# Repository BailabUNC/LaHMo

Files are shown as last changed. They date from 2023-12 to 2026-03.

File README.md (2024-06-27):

# Laryngeal Health Monitor (LaHMo)

Relevent files for the project of Laryngeal Health Monitor (LaHMo)

**arduino_firmware** The PlatformIO code for the peripheral patch and the receiver.

**CAD** The DXF files of the initial design, laser-cuttable.

**data_analysis** Relevant code of the data analysis protocol.

**data_acquisition** The python code for parsing and visualizing the data.

**models** Pre-trained models.

**results** Output figures.

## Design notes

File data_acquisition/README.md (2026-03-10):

# LaHMo BLE Data Acquisition (Desktop)

This folder contains a local desktop app that uses **bleak** to scan/connect to BLE devices (including **LaHMo2**) and plots the incoming stream in real time while logging to disk.

## Run

```bash
python -m pip install -r requirements.txt
python -m data_acquisition.app
```

## LaHMo2 defaults

- **Service UUID**: `12fb95d1-4954-450f-a82b-802f71541562`
- **Notify characteristic UUID**: `67136980-20d0-4711-8b37-3acd0fec8e7f`

The firmware sends notifications as a UTF-8 string:

`timestamp_ms,pv0_V,pv1_V,pv2_V,pv3_V,roll_deg,pitch_deg,yaw_deg`

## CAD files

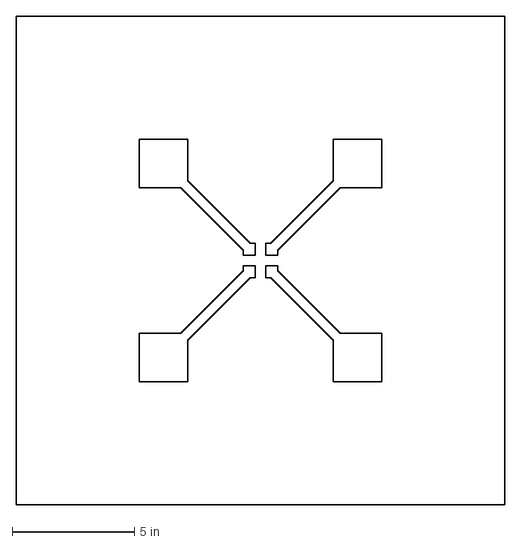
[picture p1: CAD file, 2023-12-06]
CAD/module/mosfet.dxf
20.0 x 20.0 in

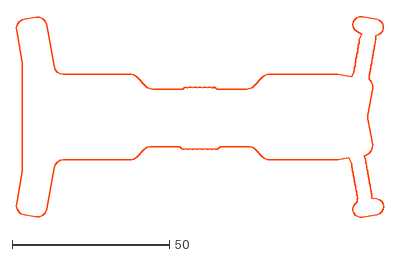
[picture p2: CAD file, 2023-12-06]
CAD/pcb_base/profile_offset.dxf
116.9 x 64.1

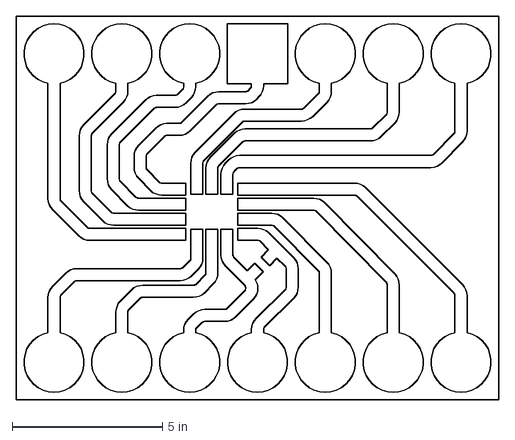
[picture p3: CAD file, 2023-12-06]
CAD/module/imu_breakout.dxf
16.0 x 12.8 in

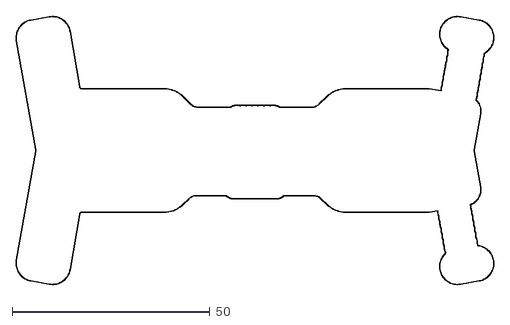
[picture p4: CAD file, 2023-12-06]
CAD/pcb_base/profile.dxf
120.8 x 67.8

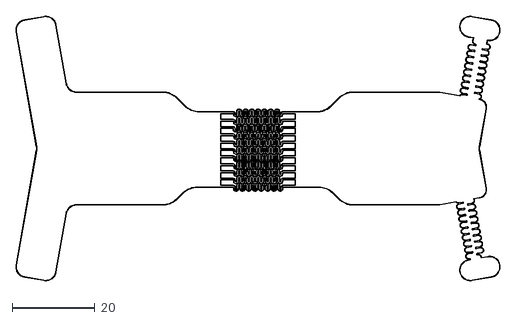
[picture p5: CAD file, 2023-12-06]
CAD/pcb_base/LSF_v3_Profile.gbr_conv.DXF
116.8 x 63.8

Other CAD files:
CAD/pcb_foldable/fold_gnd_nobranch.dwg
CAD/pcb_foldable/fold_gnd.dwg
CAD/t_shape_v3.dwg
CAD/pcb_foldable/t_shape_pi_fold_gnd.dxf
CAD/pcb_foldable/t_shape_pi.dxf
CAD/pcb_foldable/t_shape_pi_wo_marker.dxf
CAD/pcb_foldable/t_shape_pi_fold.dxf
CAD/t_shape_v2.dwg
CAD/module/mosfet.dwg
results/fig3/visualization/bevel.blend

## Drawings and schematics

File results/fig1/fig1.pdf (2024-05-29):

### PDMS

A B

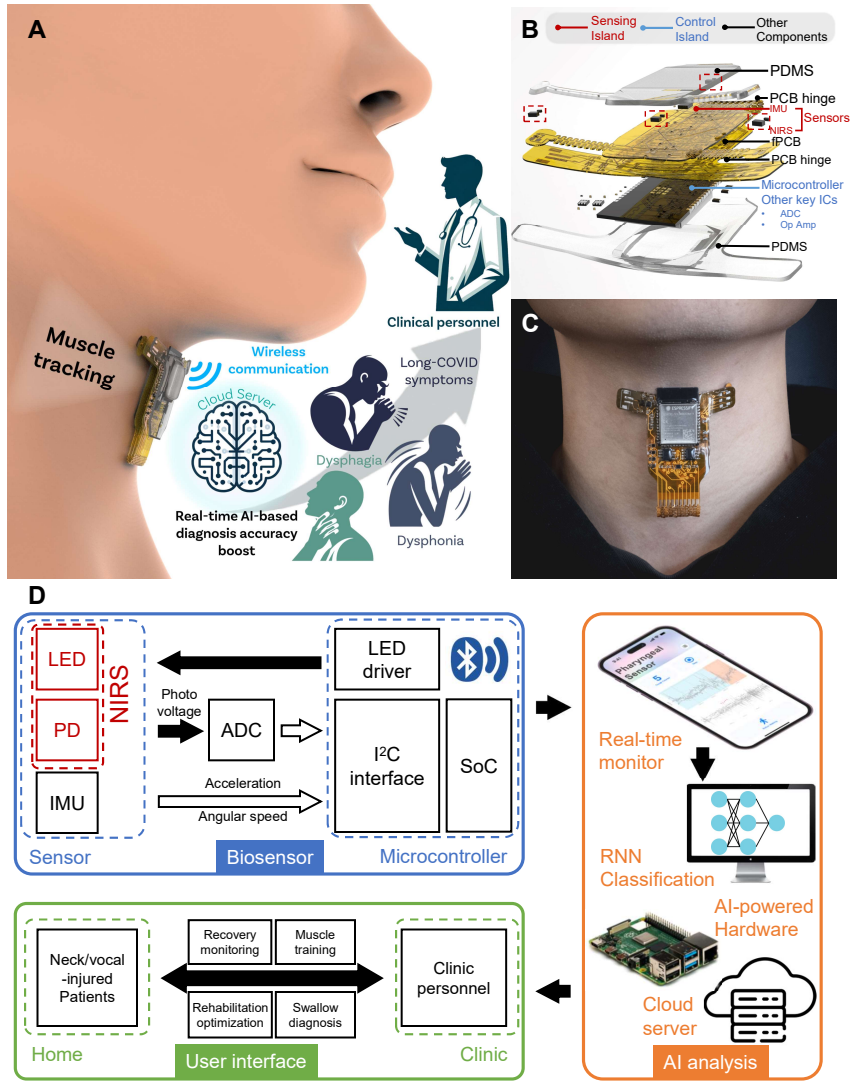
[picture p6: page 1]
Sensor; Biosensor; Microcontroller; ADC; Acceleration; Angular speed; Photo voltage; LED; IMU; SoC I²C interface; LED driver; AI analysis; RNN Classification; Real-time monitor; Cloud server; AI-powered Hardware; NIRS fPCB; User interface; Clinic personnel; Recovery monitoring; Clinic; Neck/vocal -injured Patients; Home; Rehabilitation optimization; Muscle training; Swallow diagnosis; Sensors; Sensing Island; Control Island; Other Components; PCB hinge

PCB hinge NIRS

Microcontroller
Other key ICs
• ADC
• Op Amp
PDMS

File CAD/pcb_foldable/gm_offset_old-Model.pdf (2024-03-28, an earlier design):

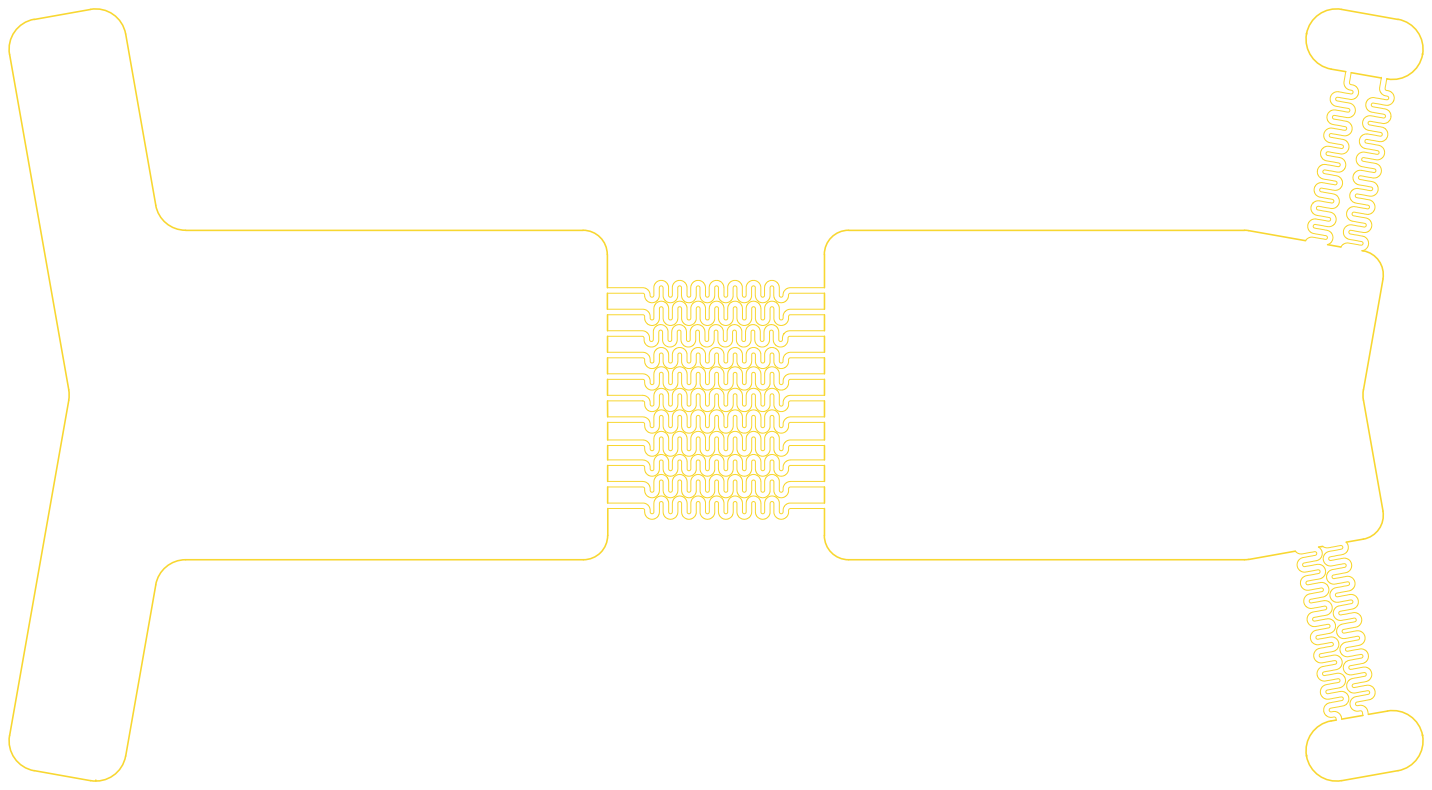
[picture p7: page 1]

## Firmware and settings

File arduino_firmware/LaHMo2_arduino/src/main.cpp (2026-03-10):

#include <Arduino.h>
#include "lahmo2.h"
#include "LSM6DSOXSensor.h"
#include "MadgwickAHRS.h"
#include "ADS1X15.h"

#include "esp_log.h"
#include "esp_wifi.h"
#include "esp_bt.h"

static const char *TAG = "MY_APP";

// PWM Configuration
#define PWM_FREQ       5000   // 5 kHz PWM frequency
#define PWM_RESOLUTION 8      // 8-bit resolution (0-255)
#define LED_DUTY_CYCLE 60     // 23.5% duty cycle (60/255)

// PWM Channels for each LED
#define LED0_CHANNEL 0
#define LED1_CHANNEL 1
#define LED2_CHANNEL 2
#define LED3_CHANNEL 3

// ADC
ADS1115 ads(MY_ADS1115_ADDRESS);
volatile bool canOutput = false;

// IMU
LSM6DSOXSensor lsm6dsox(&Wire, LSM6DSOX_I2C_ADD_L);
Madgwick filter;

// Timer
hw_timer_t               *timer;

// LED
volatile bool isLED     = true;
uint8_t stateAcc;
uint8_t stateGyr;
int32_t acc[3];
int32_t gyr[3];
int32_t acc_x, acc_y, acc_z;
int32_t gyr_x, gyr_y, gyr_z;
float roll, pitch, yaw;

// BLE connection
bool              isConnectedToClient     = false;
bool              isConnectedToLastClient = false;
BLEServer        *p_server                = nullptr;
BLECharacteristic *p_lhm_char             = nullptr;

void led_on()
{
    ledcWrite(LED0_CHANNEL, LED_DUTY_CYCLE);
    ledcWrite(LED1_CHANNEL, LED_DUTY_CYCLE);
    ledcWrite(LED2_CHANNEL, LED_DUTY_CYCLE);
    ledcWrite(LED3_CHANNEL, LED_DUTY_CYCLE);
}

void led_off()
{
    ledcWrite(LED0_CHANNEL, 0);
    ledcWrite(LED1_CHANNEL, 0);
    ledcWrite(LED2_CHANNEL, 0);
    ledcWrite(LED3_CHANNEL, 0);
}

// Connection callbacks
class MyServerCallbacks: public BLEServerCallbacks
{
    void onConnect(BLEServer *p_server)
    {
        isConnectedToClient = true;
    }
    void onDisconnect(BLEServer *p_server)
    {
        isConnectedToClient = false;
    }
};

void IRAM_ATTR onTimer()
{
    canOutput = true;
}

void ioInit()
{
    // Setup PWM channels
    ledcSetup(LED0_CHANNEL, PWM_FREQ, PWM_RESOLUTION);
    ledcSetup(LED1_CHANNEL, PWM_FREQ, PWM_RESOLUTION);
    ledcSetup(LED2_CHANNEL, PWM_FREQ, PWM_RESOLUTION);
    ledcSetup(LED3_CHANNEL, PWM_FREQ, PWM_RESOLUTION);

    // Attach PWM channels to LED pins
    ledcAttachPin(LED0, LED0_CHANNEL);
    ledcAttachPin(LED1, LED1_CHANNEL);
    ledcAttachPin(LED2, LED2_CHANNEL);
    ledcAttachPin(LED3, LED3_CHANNEL);

    led_on();
}

void peripheralInit()
{
    timer = timerBegin(0, 80, true);
    timerAttachInterrupt(timer, &onTimer, true);
    timerAlarmWrite(timer, ALARM_US, true);
    timerAlarmEnable(timer);
}

void sensorInit()
{
    delay(1000);
    Wire.begin(SDA, SCL);
    Wire.setClock(100000);

	if (!ads.isConnected())
	{
		ESP_LOGE(TAG, "Failed to initialize ADS1115.");
		while (1);
	}
	ESP_LOGI(TAG, "ADS1115 initialized.");
    ads.setMode(0);
	ads.setGain(1);
	ads.setDataRate(7);

	// Initialize IMU
	if (lsm6dsox.begin() != LSM6DSOX_OK)
    {
        ESP_LOGE(TAG, "Cannot initialize IMU!");
        while (1);
    }


	if (lsm6dsox.Enable_G() == LSM6DSOX_OK &&
		lsm6dsox.Enable_X() == LSM6DSOX_OK)
	{
		ESP_LOGI(TAG, "Success enabling accelero and gyro");
	}
	else
	{
		ESP_LOGE(TAG, "Error enabling accelero and gyro");
		while (1);
	}

	uint8_t id;
	lsm6dsox.ReadID(&id);
	if (id != LSM6DSOX_ID)
	{
		ESP_LOGE(TAG, "Wrong id for LSM6DSOX sensor. Check that device is plugged.");
        std::string info = std::to_string(id);
        // ESP_LOGE(TAG, info);
        log_printf(info.c_str());
		while (1);
	}
	else
	{
		ESP_LOGI(TAG, "Success checking id for LSM6DSOX sensor.");
	}

	// IMU setup
	lsm6dsox.Set_X_FS(2);
	lsm6dsox.Set_G_FS(250);
	lsm6dsox.Set_X_ODR(SR);
	lsm6dsox.Set_G_ODR(SR);
    lsm6dsox.Set_FIFO_Mode(LSM6DSOX_BYPASS_MODE); // flush any previous value in FIFO before start
    lsm6dsox.Set_FIFO_Mode(LSM6DSOX_STREAM_MODE); // start batching in continous mode

    // filter init
    filter.begin(1000000.0f / ALARM_US);

    ESP_LOGI(TAG, "Sensor initialized.");
}

void serviceInit()
{
    BLEDevice::init(DEVICE_NAME);
    p_server = BLEDevice::createServer();
    p_server->setCallbacks(new MyServerCallbacks());
    static BLEService *p_lhm_service = p_server->createService(LHM_SERVICE_UUID);

    p_lhm_char = p_lhm_service->createCharacteristic(
        LHM_CHAR_UUID,
        BLECharacteristic::PROPERTY_READ | BLECharacteristic::PROPERTY_NOTIFY
    );
    // Client Characteristic Configuration Descriptor (0x2902) for notifications
    p_lhm_char->addDescriptor(new BLE2902());

    p_lhm_service->start();
}

void advertisingInit()
{
    static BLEAdvertising *p_advertising = BLEDevice::getAdvertising();
    
    // set advertising data, including flags, complete list of 16-bit service UUIDs, and device name
    BLEAdvertisementData advData;
    advData.setFlags(ESP_BLE_ADV_FLAG_GEN_DISC | ESP_BLE_ADV_FLAG_BREDR_NOT_SPT);
    advData.setCompleteServices(BLEUUID(LHM_SERVICE_UUID));
    advData.setName(DEVICE_NAME);
    p_advertising->setAdvertisementData(advData);
    
    // set scan response data, including device name and other information
    BLEAdvertisementData scanRspData;
    scanRspData.setName(DEVICE_NAME);
    p_advertising->setScanResponseData(scanRspData);
    
    p_advertising->setScanResponse(true);
    p_advertising->setMinPreferred(0x06);
    
    BLEDevice::startAdvertising();
    ESP_LOGI(TAG, "Start advertising as: %s", DEVICE_NAME);
}

void setup()
{
    // Properly disable WiFi to save power (ESP-IDF style)
    esp_wifi_stop();
    esp_wifi_deinit();
    
    // Release Classic Bluetooth memory (since you only use BLE)
    esp_bt_controller_mem_release(ESP_BT_MODE_CLASSIC_BT);
    
    sensorInit();
    ioInit();
    peripheralInit();
    serviceInit();
    advertisingInit();

    ESP_LOGI(TAG, "Device started.");
}

void loop()
{   
    if (isConnectedToClient)
    {
        if (canOutput)
        {
            if (lsm6dsox.Get_X_DRDY_Status(&stateAcc) == LSM6DSOX_OK &&
                lsm6dsox.Get_G_DRDY_Status(&stateGyr) == LSM6DSOX_OK)
            {
                lsm6dsox.Get_X_Axes(acc);
                lsm6dsox.Get_G_Axes(gyr);

                acc_x = acc[0]*9.8/1000;
                acc_y = acc[1]*9.8/1000;
                acc_z = acc[2]*9.8/1000;
                gyr_x = gyr[0]/1000;
                gyr_y = gyr[1]/1000;
                gyr_z = gyr[2]/1000;

                filter.updateIMU(gyr_x, gyr_y, gyr_z, acc_x, acc_y, acc_z);
                roll = filter.getRoll();
                pitch = filter.getPitch();
                yaw = filter.getYaw();
            }

            // Read ADC values
            uint32_t timestamp = millis();
            float photovoltage0 = ads.toVoltage(ads.readADC(0));
            float photovoltage1 = ads.toVoltage(ads.readADC(1));
            float photovoltage2 = ads.toVoltage(ads.readADC(2));
            float photovoltage3 = ads.toVoltage(ads.readADC(3));

            // Convert each value to a string
            std::string timestamp_str = std::to_string(static_cast<int32_t>(timestamp));
            std::string photovoltage0_str = std::to_string(photovoltage0);
            std::string photovoltage1_str = std::to_string(photovoltage1);
            std::string photovoltage2_str = std::to_string(photovoltage2);
            std::string photovoltage3_str = std::to_string(photovoltage3);
            std::string roll_str = std::to_string(roll);
            std::string pitch_str = std::to_string(pitch);
            std::string yaw_str = std::to_string(yaw);

            // Combine all the values into a single string, separated by commas
            std::string data = timestamp_str + "," +
                               photovoltage0_str + "," +
                               photovoltage1_str + "," +
                               photovoltage2_str + "," +
                               photovoltage3_str + "," +
                               roll_str + "," +
                               pitch_str + "," +
                               yaw_str;
            p_lhm_char->setValue(data.c_str());
            p_lhm_char->notify();

            canOutput = false;            
        }
    }

    if (!isConnectedToClient && isConnectedToLastClient)
    {
        delay(500);
        p_server->startAdvertising();
        isConnectedToLastClient = isConnectedToClient;
    }

    if (isConnectedToClient && !isConnectedToLastClient)
    {
        isConnectedToLastClient = isConnectedToClient;
    }
}

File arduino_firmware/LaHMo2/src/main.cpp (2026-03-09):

#include <Arduino.h>
#include "LaHMo2.h"
#include <Adafruit_LSM6DSOX.h>
#include "MadgwickAHRS.h"
#include "ADS1X15.h"
#include "esp_log.h"

static const char *TAG = "MY_APP";

// ADC
ADS1115 ads(MY_ADS1115_ADDRESS);
volatile bool canOutput = false;

// IMU
Adafruit_LSM6DSOX lsm6dsox;
Madgwick filter;

// Timer
hw_timer_t *timer;

// LED
volatile bool isLED = true;
uint8_t stateAcc;
uint8_t stateGyr;
int32_t acc[3];
int32_t gyr[3];
int32_t acc_x, acc_y, acc_z;
int32_t gyr_x, gyr_y, gyr_z;
float roll, pitch, yaw;

// BLE connection
bool isConnectedToClient = false;
bool isConnectedToLastClient = false;
BLEService lhmService(LHM_SERVICE_UUID);
BLEStringCharacteristic lhmChar(LHM_CHAR_UUID, BLERead | BLENotify, 100);
BLEDescriptor lhmDesc(LHM_DESC_UUID, "LHM");

void led_on()
{
    digitalWrite(LED0, HIGH);
    digitalWrite(LED1, HIGH);
    digitalWrite(LED2, HIGH);
    digitalWrite(LED3, HIGH);
}

void led_off()
{
    digitalWrite(LED0, LOW);
    digitalWrite(LED1, LOW);
    digitalWrite(LED2, LOW);
    digitalWrite(LED3, LOW);
}

void IRAM_ATTR onTimer()
{
    canOutput = true;
}

void ioInit()
{
    pinMode(LED0, OUTPUT);
    pinMode(LED1, OUTPUT);
    pinMode(LED2, OUTPUT);
    pinMode(LED3, OUTPUT);

    led_on();
}

void peripheralInit()
{
    timer = timerBegin(0, 80, true);
    timerAttachInterrupt(timer, &onTimer, true);
    timerAlarmWrite(timer, ALARM_US, true);
    timerAlarmEnable(timer);
}

void sensorInit()
{
    delay(1000);
    Wire.begin(SDA, SCL);
    Wire.setClock(100000);

    if (!ads.isConnected())
    {
        ESP_LOGE(TAG, "Failed to initialize ADS1115.");
        while (1)
            ;
    }
    ESP_LOGI(TAG, "ADS1115 initialized.");
    ads.setMode(0);
    ads.setGain(1);
    ads.setDataRate(7);

    if (!lsm6dsox.begin_I2C()) {
        ESP_LOGE(TAG, "Cannot initialize IMU!");
        while (1) { delay(10); }
    }

    // Configure ranges and data rates
    lsm6dsox.setAccelRange(LSM6DS_ACCEL_RANGE_2_G);
    lsm6dsox.setGyroRange(LSM6DS_GYRO_RANGE_250_DPS);
    // Map SR (Hz) to sensor settings. Using SR defined (e.g., 6667 Hz) is above sensor capability; choose closest valid (e.g., 6.66 kHz not supported). We'll select 1.66 kHz for both.
    lsm6dsox.setAccelDataRate(LSM6DS_RATE_1660_HZ);
    lsm6dsox.setGyroDataRate(LSM6DS_RATE_1660_HZ);
    ESP_LOGI(TAG, "LSM6DSOX initialized with 1660 Hz ODR.");

    filter.begin(1000000.0f / ALARM_US);

    ESP_LOGI(TAG, "Sensor initialized.");
}

void serviceInit()
{
    if (!BLE.begin())
    {
        ESP_LOGE(TAG, "starting BLE failed!");
        while (1)
            ;
    }

    BLE.setLocalName(DEVICE_NAME);
    BLE.setAdvertisedService(lhmService);

    lhmService.addCharacteristic(lhmChar);
    lhmChar.addDescriptor(lhmDesc);
    BLE.addService(lhmService);
}

void advertisingInit()
{
    BLE.advertise();
    ESP_LOGV(TAG, "Start advertising.");
}

void setup()
{
    sensorInit();
    ioInit();
    peripheralInit();
    serviceInit();
    advertisingInit();

    ESP_LOGI(TAG, "Device started.");
}

void loop()
{
    BLEDevice central = BLE.central();

    if (central)
    {
        isConnectedToClient = true;
        while (central.connected())
        {
            if (canOutput)
            {
                sensors_event_t accel;  
                sensors_event_t gyro;   
                sensors_event_t temp;   
                lsm6dsox.getEvent(&accel, &gyro, &temp);

                acc_x = accel.acceleration.x; // m/s^2
                acc_y = accel.acceleration.y;
                acc_z = accel.acceleration.z;
                // Arduino Madgwick library expects gyroscope data in degrees/second.
                gyr_x = gyro.gyro.x * 57.295779513; // rad/s -> deg/s
                gyr_y = gyro.gyro.y * 57.295779513;
                gyr_z = gyro.gyro.z * 57.295779513;

                filter.updateIMU(gyr_x, gyr_y, gyr_z, acc_x, acc_y, acc_z);
                roll = filter.getRoll();
                pitch = filter.getPitch();
                yaw = filter.getYaw();

                uint32_t timestamp = millis();
                float photovoltage0 = ads.toVoltage(ads.readADC(0));
                float photovoltage1 = ads.toVoltage(ads.readADC(1));
                float photovoltage2 = ads.toVoltage(ads.readADC(2));
                float photovoltage3 = ads.toVoltage(ads.readADC(3));

                std::string timestamp_str = std::to_string(static_cast<int32_t>(timestamp));
                std::string photovoltage0_str = std::to_string(photovoltage0);
                std::string photovoltage1_str = std::to_string(photovoltage1);
                std::string photovoltage2_str = std::to_string(photovoltage2);
                std::string photovoltage3_str = std::to_string(photovoltage3);
                std::string roll_str = std::to_string(roll);
                std::string pitch_str = std::to_string(pitch);
                std::string yaw_str = std::to_string(yaw);

                std::string data = timestamp_str + "," +
                                   photovoltage0_str + "," +
                                   photovoltage1_str + "," +
                                   photovoltage2_str + "," +
                                   photovoltage3_str + "," +
                                   roll_str + "," +
                                   pitch_str + "," +
                                   yaw_str;

                lhmChar.writeValue(data.c_str());

                canOutput = false;
            }

            BLE.poll();
        }
        isConnectedToClient = false;
    }

    if (!isConnectedToClient && isConnectedToLastClient)
    {
        delay(500);
        BLE.advertise();
        isConnectedToLastClient = isConnectedToClient;
    }

    if (isConnectedToClient && !isConnectedToLastClient)
    {
        isConnectedToLastClient = isConnectedToClient;
    }
}

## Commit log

2023-03-09 electric designs
    [t_shape_pi.dxf, t_shape_pi_fold.dxf, t_shape_pi_wo_marker.dxf]
2023-11-27 ble data
    [deep_breath.csv, dry_cough.csv, jumping_jack.csv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]
2023-12-04 Uploaded t_shape_plotter_2 and its dataset.
    [interp_data.csv]
2023-12-05 CAD files of the customized PCB
    [LSF_v3_Profile.gbr_conv.DXF, fold_gnd.dwg, fold_gnd_nobranch.dwg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]
2023-12-06 organize dataset
    [ble_long_1.csv, ble_long_2.csv, breathing.csv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]
2023-12-13 update the name of the filter_windows()
2023-12-13 update the comment of the filter_windows()
2023-12-19 fine tuning parameters
    [1.csv, 2.csv, bevel.blend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]
2024-01-23 add results
    [interpolated.csv]
2024-02-05 basketball data
    [test-2024-01-08-13-35-36.csv, test-2024-01-10-16-01-28.csv]
2024-02-16 cough events
    [data_points.csv]
2024-03-26 update dataset
    [test-2024-01-17-02-18-45.csv, test-2024-01-17-03-45-51.csv, test-2024-01-19-16-08-05.csv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]
2024-03-26 organize top directory
    [interp_data.csv]
2024-03-26 organize files
    [interp_data.csv, interp_data_1.csv]
2024-06-27 update cad
    [t_shape_v2.dwg]
2024-08-06 update to LaHMo2
    [t_shape_v2.dwg, t_shape_v3.dwg]
2024-08-08 pnas revision
    [test-2024-08-07-21-32-09.csv, test-2024-08-07-21-35-59.csv, test-2024-08-07-21-39-56.csv]
2024-08-13 revision firmware and test update
    [test-2024-08-12-16-33-28.csv, test-2024-08-12-16-47-18.csv]
2024-08-23 revision update
    [test-2024-08-23-11-29-31.csv, test-2024-08-24-11-31-59.csv]
2024-09-05 add video data
    [test-2024-09-05-12-00-15.csv, test-2024-09-06-12-05-55.csv]
2024-09-24 major revision
    [test-2024-09-10-16-52-05.csv]
2024-09-24 monte-carlo simulation
    [adams_apple_locations.xlsx]
2025-08-21 arduino wrap up
2025-08-21 Add ArduinoBLE-based firmware
2025-08-21 start a new arduino project to implement BLE with ArduinoBLE.h
2025-08-21 feat: add ArduinoBLE firmware for LaHMo2
2026-03-09 update arduino firmware
2026-03-10 update arduino firmware
    Enable BLE notifications for LaHMo2_arduino so desktop clients can subscribe without write-permission errors.
    Made-with: Cursor
    [lahmo2.h, main.cpp]
2026-03-10 add desktop BLE acquisition GUI
    Replace the legacy serial tools with a bleak-based MVC desktop app that scans nearby devices, streams live plots, and logs sessions locally.
    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
2026-03-10 delete old firmware
    Remove legacy receiver firmware directories that are no longer used after the BLE desktop acquisition workflow replaced them.
    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
    [main.cpp]
